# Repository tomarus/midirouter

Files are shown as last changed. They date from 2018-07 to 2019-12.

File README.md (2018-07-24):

FPGA/Verilog MIDI Mixer
=======================

See also: 

* https://github.com/tomarus/v-midi
* https://github.com/tomarus/midiseq

This is a "production" version of my FPGA MIDI router.

My v-midi project is more experimental, this one is tuned for my own hardware.

# Disclaimer

Do not use this to learn Verilog or FPGA stuff.

This is my own personal experimental project.

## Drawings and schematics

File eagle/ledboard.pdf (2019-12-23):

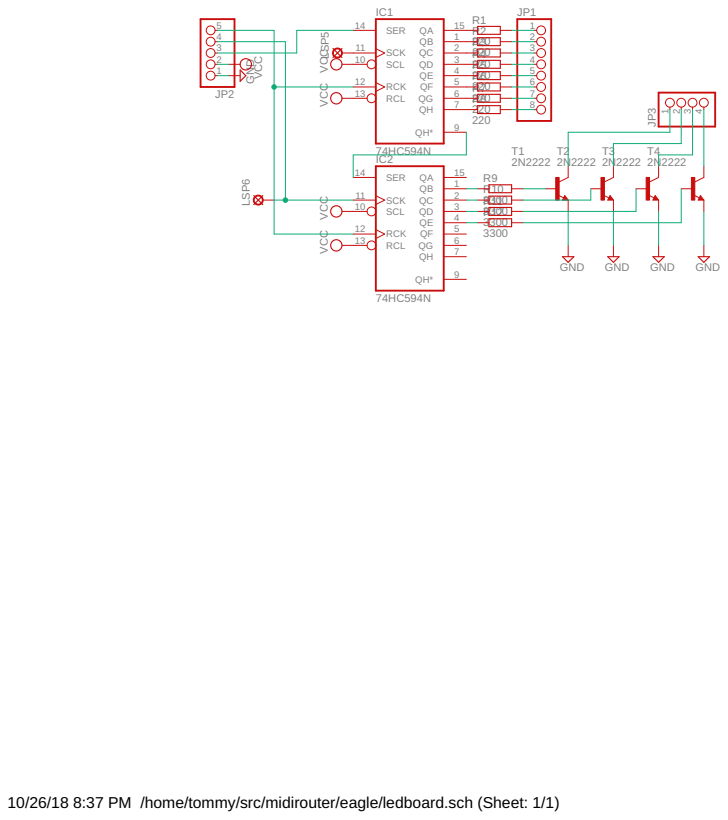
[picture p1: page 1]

VCC VCC

220 R4 3 QE
220 R5 4 QF

10/26/18 8:37 PM /home/tommy/src/midirouter/eagle/ledboard.sch (Sheet: 1/1)

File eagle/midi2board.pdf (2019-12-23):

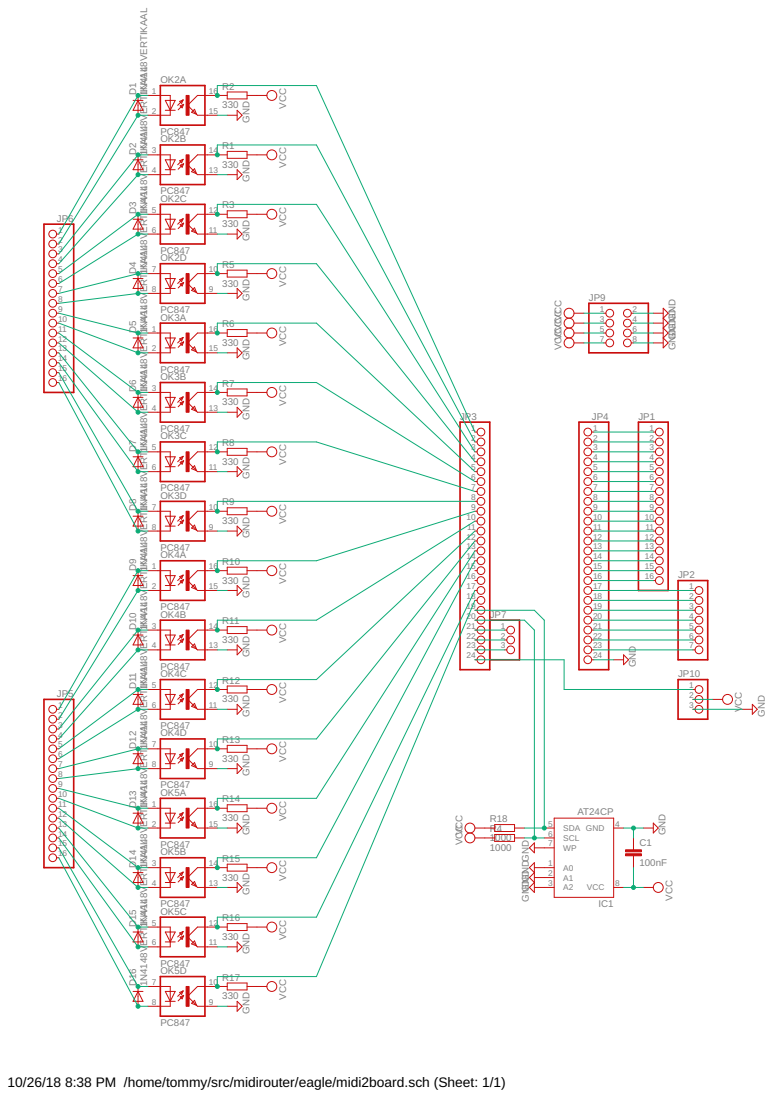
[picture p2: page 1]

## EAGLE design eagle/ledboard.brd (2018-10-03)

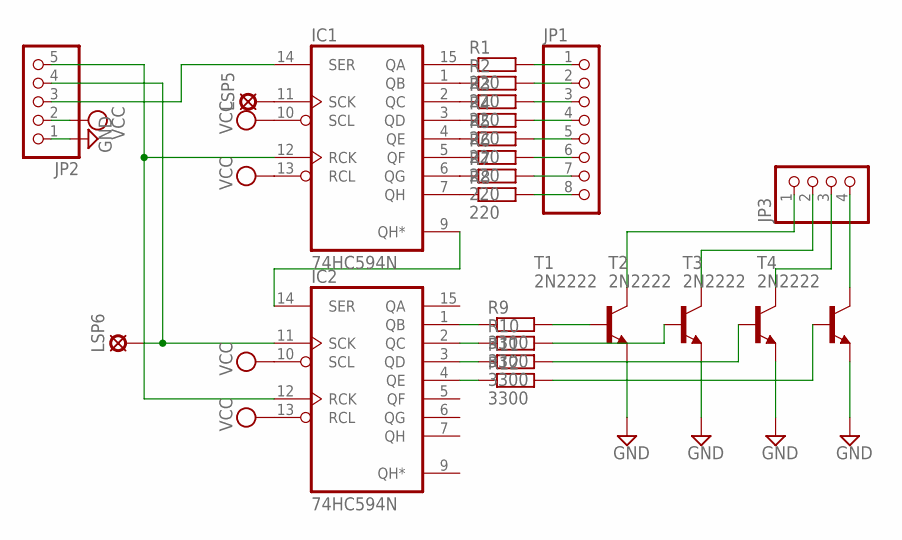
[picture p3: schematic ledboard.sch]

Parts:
IC1, IC2: 74HC594N; DIL16
JP1: PINHD-1X8; 1X08
JP2: PINHD-1X5; 1X05
JP3: PINHD-1X4; 1X04
LSP5, LSP6: LSP10
R1, R2, R3, R4, R5, R6, R7, R8: 220; 0207/10
R9, R10, R11, R12: 3300; 0207/10
T1, T2, T3, T4: 2N2222; TO92-EBC-OVAL

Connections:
GND: IC1.8 (GND), IC2.8 (GND), JP2.1, T1.E, T2.E, T3.E, T4.E
unnamed: IC1.14 (SER), JP2.3
unnamed: IC1.11 (SCK), LSP5.MP
unnamed: IC1.15 (QA), R1.1
unnamed: IC1.1 (QB), R2.1
unnamed: IC1.2 (QC), R3.1
unnamed: IC1.3 (QD), R4.1
unnamed: IC1.4 (QE), R5.1
unnamed: IC1.5 (QF), R6.1
unnamed: IC1.6 (QG), R7.1
unnamed: IC1.7 (QH), R8.1
unnamed: IC2.3 (QD), R11.1
unnamed: IC2.2 (QC), R10.1
unnamed: IC2.1 (QB), R9.1
unnamed: IC2.4 (QE), R12.1
unnamed: R9.2, T1.B
unnamed: R10.2, T2.B
unnamed: R11.2, T3.B
unnamed: R12.2, T4.B
unnamed: JP1.1, R1.2
unnamed: JP1.2, R2.2
unnamed: JP1.3, R3.2
unnamed: JP1.4, R4.2
unnamed: JP1.5, R5.2
unnamed: JP1.6, R6.2
unnamed: JP1.7, R7.2
unnamed: JP1.8, R8.2
unnamed: JP3.1, T1.C
unnamed: JP3.2, T2.C
unnamed: JP3.3, T3.C
unnamed: JP3.4, T4.C
unnamed: IC2.11 (SCK), JP2.4, LSP6.MP
unnamed: IC1.12 (RCK), IC2.12 (RCK), JP2.5
unnamed: IC1.9 (QH*), IC2.14 (SER)
VCC: IC1.10 (SCL), IC1.13 (RCL), IC1.16 (VCC), IC2.10 (SCL), IC2.13 (RCL), IC2.16 (VCC), JP2.2

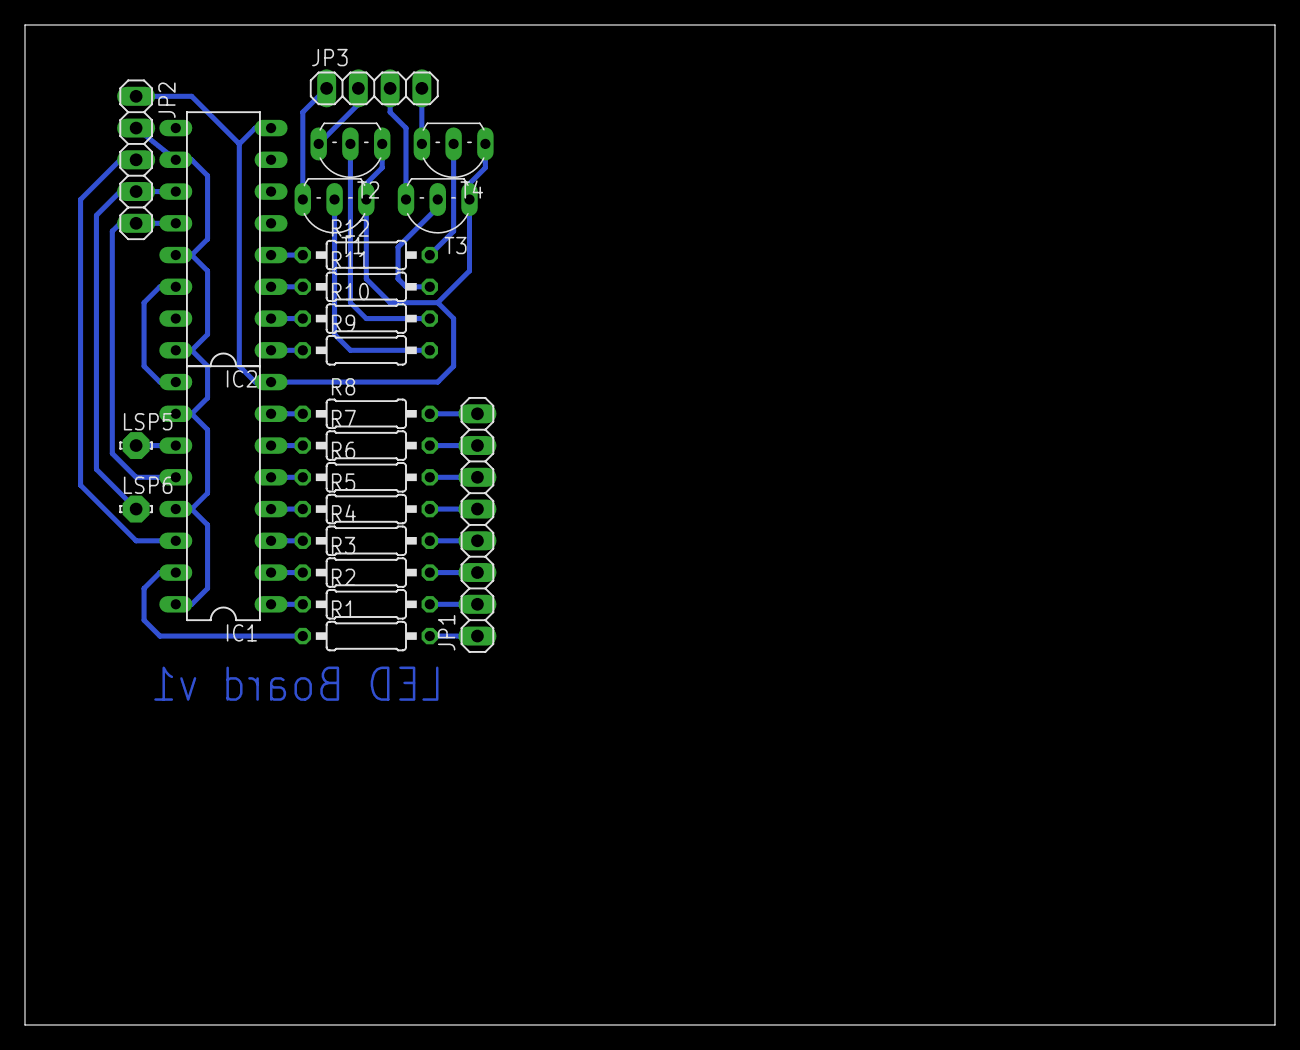
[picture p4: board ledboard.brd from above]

Board: 2 copper layers, 100.0 x 80.0 mm, 23 parts (0 on the bottom side), 35 nets.

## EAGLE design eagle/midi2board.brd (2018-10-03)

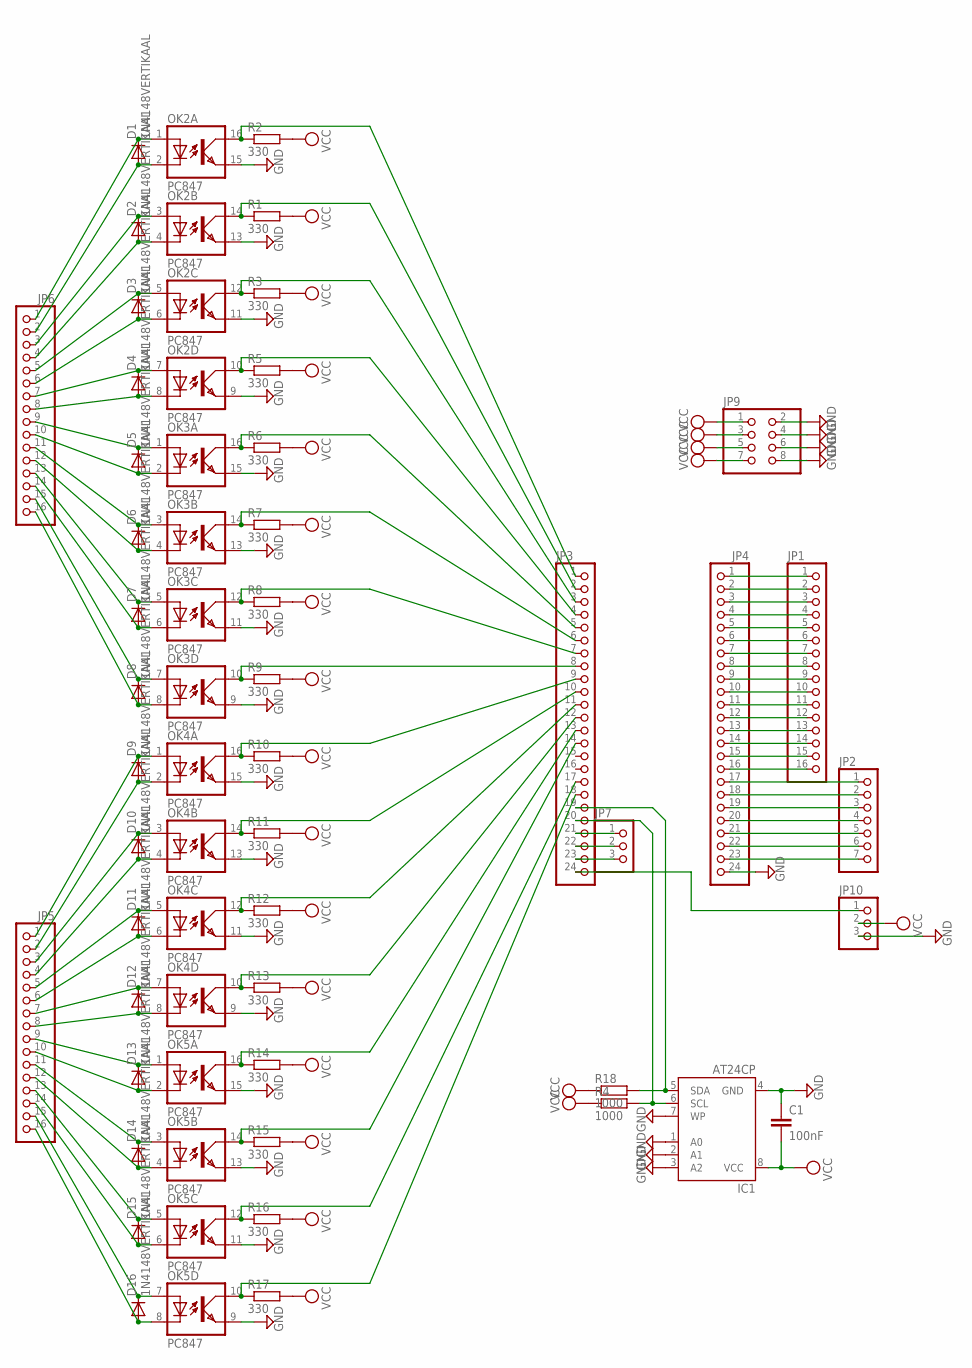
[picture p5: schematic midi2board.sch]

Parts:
C1: 100nF; C5B2.5
D1, D2, D3, D4, D5, D6, D7, D8, D9, D10, D11, D12, D13, D14, D15, D16: 1N4148VERTIKAAL; RAD2,5
IC1: AT24CP; DIL08
JP1, JP5, JP6: PINHD-1X16; 1X16
JP2: PINHD-1X7; 1X07
JP3, JP4: PINHD-1X24; 1X24
JP7, JP10: PINHD-1X3; 1X03
JP9: PINHD-2X4; 2X04
OK2, OK3, OK4, OK5: PC847; DIL16
R1, R2, R3, R5, R6, R7, R8, R9, R10, R11, R12, R13, R14, R15, R16, R17: 330; 0207/10
R4, R18: 1000; 0207/10

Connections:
GND: C1.1, IC1.1 (A0), IC1.2 (A1), IC1.3 (A2), IC1.4 (GND), IC1.7 (WP), JP4.24, JP9.2, JP9.4, JP9.6, JP9.8, JP10.3, OK2.9 (EMIT), OK2.11 (EMIT), OK2.13 (EMIT), OK2.15 (EMIT), OK3.9 (EMIT), OK3.11 (EMIT), OK3.13 (EMIT), OK3.15 (EMIT), OK4.9 (EMIT), OK4.11 (EMIT), OK4.13 (EMIT), OK4.15 (EMIT), OK5.9 (EMIT), OK5.11 (EMIT), OK5.13 (EMIT), OK5.15 (EMIT)
unnamed: JP2.1, JP4.17
unnamed: D1.C, JP6.1, OK2.1 (A)
unnamed: D1.A, JP6.2, OK2.2 (C)
unnamed: JP2.2, JP4.18
unnamed: JP2.3, JP4.19
unnamed: D2.C, JP6.3, OK2.3 (A)
unnamed: D2.A, JP6.4, OK2.4 (C)
unnamed: JP2.4, JP4.20
unnamed: D3.C, JP6.5, OK2.5 (A)
unnamed: D3.A, JP6.6, OK2.6 (C)
unnamed: D4.C, JP6.7, OK2.7 (A)
unnamed: D4.A, JP6.8, OK2.8 (C)
unnamed: D5.C, JP6.9, OK3.1 (A)
unnamed: D5.A, JP6.10, OK3.2 (C)
unnamed: D6.C, JP6.11, OK3.3 (A)
unnamed: D6.A, JP6.12, OK3.4 (C)
unnamed: D7.C, JP6.13, OK3.5 (A)
unnamed: D7.A, JP6.14, OK3.6 (C)
unnamed: D8.C, JP6.15, OK3.7 (A)
unnamed: D8.A, JP6.16, OK3.8 (C)
unnamed: D9.C, JP5.1, OK4.1 (A)
unnamed: D9.A, JP5.2, OK4.2 (C)
unnamed: D10.C, JP5.3, OK4.3 (A)
unnamed: D10.A, JP5.4, OK4.4 (C)
unnamed: D11.C, JP5.5, OK4.5 (A)
unnamed: D11.A, JP5.6, OK4.6 (C)
unnamed: D12.C, JP5.7, OK4.7 (A)
unnamed: D12.A, JP5.8, OK4.8 (C)
unnamed: D13.C, JP5.9, OK5.1 (A)
unnamed: D13.A, JP5.10, OK5.2 (C)
unnamed: D14.C, JP5.11, OK5.3 (A)
unnamed: D14.A, JP5.12, OK5.4 (C)
unnamed: D15.C, JP5.13, OK5.5 (A)
unnamed: D15.A, JP5.14, OK5.6 (C)
unnamed: D16.C, JP5.15, OK5.7 (A)
unnamed: D16.A, JP5.16, OK5.8 (C)
unnamed: JP3.2, OK2.14 (COL), R1.1
unnamed: JP3.1, OK2.16 (COL), R2.1
unnamed: JP3.3, OK2.12 (COL), R3.1
unnamed: JP3.4, OK2.10 (COL), R5.1
unnamed: JP3.5, OK3.16 (COL), R6.1
unnamed: JP3.6, OK3.14 (COL), R7.1
unnamed: JP3.7, OK3.12 (COL), R8.1
unnamed: JP3.8, OK3.10 (COL), R9.1
unnamed: JP3.9, OK4.16 (COL), R10.1
unnamed: JP3.10, OK4.14 (COL), R11.1
unnamed: JP3.11, OK4.12 (COL), R12.1
unnamed: JP3.12, OK4.10 (COL), R13.1
unnamed: JP3.13, OK5.16 (COL), R14.1
unnamed: JP3.14, OK5.14 (COL), R15.1
unnamed: JP3.17, OK5.12 (COL), R16.1
unnamed: JP3.18, OK5.10 (COL), R17.1
unnamed: JP3.24, JP10.1
unnamed: JP3.21, JP7.1
unnamed: JP3.22, JP7.2
unnamed: JP3.23, JP7.3
unnamed: JP1.1, JP4.1
unnamed: JP1.2, JP4.2
unnamed: JP1.3, JP4.3
unnamed: JP1.4, JP4.4
unnamed: JP1.5, JP4.5
unnamed: JP1.6, JP4.6
unnamed: JP1.7, JP4.7
unnamed: JP1.8, JP4.8
unnamed: JP1.9, JP4.9
unnamed: JP1.10, JP4.10
unnamed: JP1.11, JP4.11
unnamed: JP1.12, JP4.12
unnamed: JP1.13, JP4.13
unnamed: JP1.14, JP4.14
unnamed: JP1.15, JP4.15
unnamed: JP1.16, JP4.16
unnamed: JP2.5, JP4.21
unnamed: JP2.6, JP4.22
unnamed: JP2.7, JP4.23
unnamed: IC1.5 (SDA), JP3.19, R18.2
unnamed: IC1.6 (SCL), JP3.20, R4.2
VCC: C1.2, IC1.8 (VCC), JP9.1, JP9.3, JP9.5, JP9.7, JP10.2, R1.2, R2.2, R3.2, R4.1, R5.2, R6.2, R7.2, R8.2, R9.2, R10.2, R11.2, R12.2, R13.2, R14.2, R15.2, R16.2, R17.2, R18.1

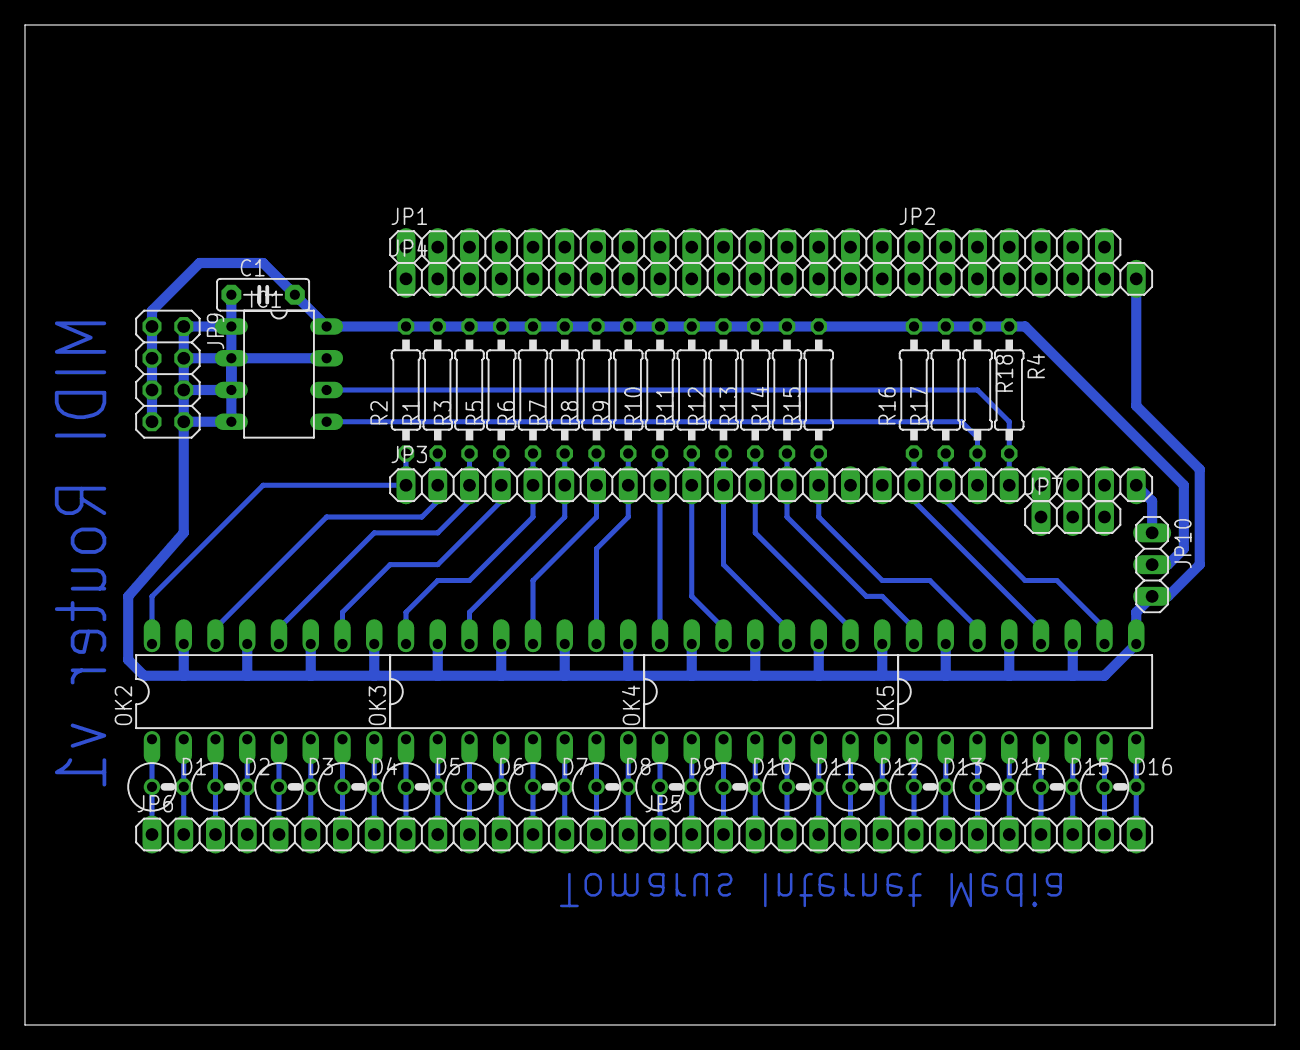
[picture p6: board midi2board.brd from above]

Board: 2 copper layers, 100.0 x 80.0 mm, 49 parts (0 on the bottom side), 79 nets.

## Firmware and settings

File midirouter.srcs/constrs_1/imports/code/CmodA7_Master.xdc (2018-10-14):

## This file is a general .xdc for the CmodA7 rev. B
## To use it in a project:
## - uncomment the lines corresponding to used pins
## - rename the used ports (in each line, after get_ports) according to the top level signal names in the project

## Clock signal 12 MHz
set_property -dict {PACKAGE_PIN L17 IOSTANDARD LVCMOS33} [get_ports clk]
create_clock -period 83.330 -name sys_clk_pin -waveform {0.000 41.660} -add [get_ports clk]


## LEDs
set_property -dict {PACKAGE_PIN A17 IOSTANDARD LVCMOS33} [get_ports {led[0]}]
set_property -dict {PACKAGE_PIN C16 IOSTANDARD LVCMOS33} [get_ports {led[1]}]

set_property -dict { PACKAGE_PIN B17   IOSTANDARD LVCMOS33 } [get_ports { led0_b }]; #IO_L14N_T2_SRCC_16 Sch=led0_b
set_property -dict { PACKAGE_PIN B16   IOSTANDARD LVCMOS33 } [get_ports { led0_g }]; #IO_L13N_T2_MRCC_16 Sch=led0_g
set_property -dict { PACKAGE_PIN C17   IOSTANDARD LVCMOS33 } [get_ports { led0_r }]; #IO_L14P_T2_SRCC_16 Sch=led0_r


## Buttons
#set_property -dict { PACKAGE_PIN A18   IOSTANDARD LVCMOS33 } [get_ports { btn[0] }]; #IO_L19N_T3_VREF_16 Sch=btn[0]
#set_property -dict { PACKAGE_PIN B18   IOSTANDARD LVCMOS33 } [get_ports { btn[1] }]; #IO_L19P_T3_16 Sch=btn[1]


## Pmod Header JA
#set_property -dict { PACKAGE_PIN G17   IOSTANDARD LVCMOS33 } [get_ports { ja[0] }]; #IO_L5N_T0_D07_14 Sch=ja[1]
#set_property -dict { PACKAGE_PIN G19   IOSTANDARD LVCMOS33 } [get_ports { ja[1] }]; #IO_L4N_T0_D05_14 Sch=ja[2]
#set_property -dict { PACKAGE_PIN N18   IOSTANDARD LVCMOS33 } [get_ports { ja[2] }]; #IO_L9P_T1_DQS_14 Sch=ja[3]
#set_property -dict { PACKAGE_PIN L18   IOSTANDARD LVCMOS33 } [get_ports { ja[3] }]; #IO_L8P_T1_D11_14 Sch=ja[4]
#set_property -dict { PACKAGE_PIN H17   IOSTANDARD LVCMOS33 } [get_ports { ja[4] }]; #IO_L5P_T0_D06_14 Sch=ja[7]
#set_property -dict { PACKAGE_PIN H19   IOSTANDARD LVCMOS33 } [get_ports { ja[5] }]; #IO_L4P_T0_D04_14 Sch=ja[8]
#set_property -dict { PACKAGE_PIN J19   IOSTANDARD LVCMOS33 } [get_ports { ja[6] }]; #IO_L6N_T0_D08_VREF_14 Sch=ja[9]
#set_property -dict { PACKAGE_PIN K18   IOSTANDARD LVCMOS33 } [get_ports { ja[7] }]; #IO_L8N_T1_D12_14 Sch=ja[10]


## Analog XADC Pins
## Only declare these if you want to use pins 15 and 16 as single ended analog inputs. pin 15 -> vaux4, pin16 -> vaux12
#set_property -dict { PACKAGE_PIN G2    IOSTANDARD LVCMOS33 } [get_ports { xa_n[0] }]; #IO_L1N_T0_AD4N_35 Sch=ain_n[15]
#set_property -dict { PACKAGE_PIN G3    IOSTANDARD LVCMOS33 } [get_ports { xa_p[0] }]; #IO_L1P_T0_AD4P_35 Sch=ain_p[15]
#set_property -dict { PACKAGE_PIN J2    IOSTANDARD LVCMOS33 } [get_ports { xa_n[1] }]; #IO_L2N_T0_AD12N_35 Sch=ain_n[16]
#set_property -dict { PACKAGE_PIN H2    IOSTANDARD LVCMOS33 } [get_ports { xa_p[1] }]; #IO_L2P_T0_AD12P_35 Sch=ain_p[16]
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

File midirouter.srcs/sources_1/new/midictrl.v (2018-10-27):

`timescale 1ns / 1ps
// Create Date: 07/06/2018 12:52:50 PM
// Module Name: midictrl

module midictrl #( 
	parameter PORTS = 16,
	parameter CLKS_PER_BIT = 384
) (
	input   clk,
	input   rst,
	input   [PORTS-1:0] inport,
	output  [PORTS-1:0] outport,
	output  [PORTS-1:0] activity_in,
	output  [PORTS-1:0] activity_out
);

reg  [PORTS-1:0]   txdv = 0;
reg  [PORTS*8-1:0] txdata = 0;
wire [PORTS*8-1:0] rxdata;
reg  [PORTS*4-1:0] txcurport = 0;
wire [PORTS-1:0]   rx_empty;
reg  [PORTS-1:0]   rx_rden = 0;

reg [15:0] ledclk;
reg ledclken;
always @(posedge clk) begin
	ledclk <= ledclk + 1;
	if (ledclk == 0) ledclken <= 1;
	else ledclken <= 0;
end

midi_port #(.CLKS_PER_BIT(CLKS_PER_BIT), .PORTS(PORTS)) 
	ports[PORTS-1:0] 
	(clk, rst, txdv, outport, txdata, inport, rxdata, activity_in, activity_out, txcurport, rx_empty, rx_rden, ledclken);

reg [63:0] cfg_in_filter = 64'hffffffffffffffff;
reg [63:0] cfg_in_router = 64'hffffffffffffffff;

reg [4:0]port = 0;

reg reset_running = 0;
reg [3:0] reset_counter = 0;
reg [3:0] chcnt = 0;
reg [2:0] msgcnt = 0;

reg sysex_running = 0;
reg [16*8-1:0] sxdata = 0; // 16 * 8 bits of sysex command max
reg [4:0] sxpos = 0;

reg [PORTS*2-1:0] portstate = 0;

reg [3:0] checkport = 2;
reg [2:0] checkstate = 0;

always @(posedge clk)
begin
	txdv[PORTS-1:0] <= 0;

	if (reset_running)
		runreset();
	else if (rst) begin
		reset_counter <= 0;
		// reset_running <= 1;
		chcnt <= 0;
		msgcnt <= 0;
	end
	else begin
		if (sysex_running) runsysex();

		case (checkstate)
		3'b000: begin
			checkport <= checkport + 1;
			if (checkport == 6) begin
				checkport <= 8;
			end
			checkstate <= 3'b001;
		end
		3'b001: begin
			if (!rx_empty[checkport]) begin
				rx_rden[checkport] <= 1;
				checkstate <= 3'b010;
			end
			else begin
				rx_rden[checkport] <= 0;
				checkstate <= 3'b000;
			end
		end
		3'b010: begin
			rx_rden[checkport] <= 0;
			checkstate <= 3'b011;
		end
		3'b011: begin
			handlebyte(checkport, rxdata[checkport*8+:8], portstate[checkport*2+:2]);
			checkstate <= 3'b100;
		end
		3'b100: begin
			checkstate <= 3'b000;
		end
		default: begin
			checkstate <= 3'b000;
		end
		endcase
	end
end

localparam s_IDLE = 2'b00;
localparam s_DATA = 2'b01;
localparam s_SYSEX = 2'b10;

localparam sx_BEGIN = 2'b00;
localparam sx_ID1 = 2'b01;
localparam sx_ID2 = 2'b10;
localparam sx_BUF = 2'b11;
reg [PORTS*2-1:0] sxstate = 0;

task handlebyte;
input [3:0] port;
input [7:0] inbyte;
input [1:0] state;
begin
	case (inbyte[7])
	// command
	1'b1:
		begin
			case (inbyte[7:0])
			8'hff: ; // ignore system reset
			8'hfe: ; // ignore active sensing
			8'hf0: begin
				portstate[port*2+:2] <= s_SYSEX;
				sxstate[port*2+:2] <= sx_BEGIN;
				notallportmsg(inbyte, port);
			end
			8'hf7: begin
				portstate[port*2+:2] <= s_IDLE;
				sysex_running <= 1;
				reset_counter <= 0;
				chcnt <= 0;
				notallportmsg(inbyte, port);
			end
			default: begin
				notallportmsg(inbyte, port);
			end
			endcase
		end
	 // data
	 1'b0:
		begin
			notallportmsg(inbyte, port);

			case (state[1:0])
//            s_IDLE:
//            s_DATA:
			s_SYSEX:
				begin
				 handlesysex(port, inbyte[7:0]);
				end
			default: ;
			endcase
		end
	endcase
end
endtask

//  output.send
//      0xf0, 0x7d,        // sysex, non commercial / educational manufacturer id.
//      0x2a, 0x4d,        // my own little secret magic number id for this router.
//      0x00,              // COMMAND 0x00 = request sysex config dump.
//      0xf7
//  response = 0xf0, 0x7d, 0x2a, 0x4d,
//      0x40, 0x01,            // RESPONSE 0x40, version 1
//      0x01, 0x02,            // 1 inport, 2 outports
//      byte(int(bpm) >> 7),   // current speet msb
//      byte(int(bpm) & 0x7f), // current speed lsb
//      0xf7

reg [11*8-1:0] cfg = 88'hf0_7d_2a_4d_40_01_0f_0f_00_70_f7;

reg [13:0] sxdelay = 0;

task runsysex;
begin
	if (sxpos == 0 || sxdata[7:0] != 0) begin // cnd 0 = request config dunp
//    if (sxpos == 0) begin // cnd 0 = request config dunp
		sysex_running <= 0;
	end
	else begin
		sxdelay <= sxdelay + 1;
		if (sxdelay == 3840) begin
			sxdelay <= 0;
			allportmsg(cfg[(11-reset_counter)*8+:8]);
			reset_counter <= reset_counter + 1;
			if (reset_counter == 4'd11) begin
				sysex_running <= 0;
			end
		end
	end
end
endtask

task handlesysex;
input [3:0]port;
input [7:0]inbyte;
begin
   case (sxstate[port*2+:2])
	sx_BEGIN: begin
		if (inbyte[7:0] == 8'h7d) sxstate[port*2+:2] <= sx_ID1;
	end
	sx_ID1: begin
		if (inbyte[7:0] == 8'h2a) sxstate[port*2+:2] <= sx_ID2;
	end
	sx_ID2: begin
		if (inbyte[7:0] == 8'h4d) begin
			sxstate[port*2+:2] <= sx_BUF;
			sxpos[4:0] <= 0;
		end
	end
	sx_BUF:
		begin
			sxdata[sxpos*8+:8] <= inbyte[7:0];
			sxpos <= sxpos + 1;
		end
	endcase
end
endtask

// reset

task runreset;
begin
	sxdelay <= sxdelay + 1;
	if (sxdelay == 3840) begin
		sxdelay <= 0;
	case (reset_counter)
	4'h0: begin
		allportmsg(8'hfc);
		reset_counter <= reset_counter + 1;
	end
	4'h1: begin
		allportallchmsg(8'hb0, 8'h78, 8'h00); // All sound off
	end
	4'h2: begin
		allportallchmsg(8'hb0, 8'h79, 8'h00); // Reset all controllers
	end
	4'h3: begin
		allportallchmsg(8'hb0, 8'h7b, 8'h00); // All notes off
	end
	4'h4: begin
		reset_running <= 0;
	end
	default:
		reset_running <= 0;
	endcase
	end
end
endtask

task allportallchmsg;
input [7:0]msg1, msg2, msg3;
begin
	case (msgcnt)
	3'b000: begin
		allportmsg(msg1 + chcnt);
		msgcnt <= msgcnt + 1;
	end
	3'b001: begin
		allportmsg(msg2);
		msgcnt <= msgcnt + 1;
	end
	3'b010: begin
		allportmsg(msg3);
		msgcnt <= 0;

		if (chcnt == 4'd15) begin
			reset_counter <= reset_counter + 1;
			chcnt <= 0;
		end
		else begin
			chcnt <= chcnt + 1;
		end
	end
	default:
		msgcnt <= 0;
	endcase
end
endtask

reg [4:0]port_apmsg = 0;
task allportmsg;
input [7:0]msg;
	for (port_apmsg=0; port_apmsg<PORTS; port_apmsg=port_apmsg+1) begin
		sendbyte(port_apmsg, msg, -1); // TODO: -1
	end
endtask

task notallportmsg;
input [7:0]msg;
input [3:0]current_port;
	for (port_apmsg=0; port_apmsg<PORTS; port_apmsg=port_apmsg+1) begin
		if (port_apmsg != current_port) begin
			sendbyte(port_apmsg, msg, current_port);
		end
	end
endtask

task sendbyte;
input [3:0] port;
input [7:0] inbyte;
input [3:0] srcport;
begin
	txdata[port*8+:8] <= inbyte[7:0];
	txdv[port] <= 1;
	txcurport[port*4+:4] <= srcport[3:0];
end
endtask

endmodule

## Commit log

2018-07-25 Fix some small stuff.
    [midictrl.v]
2018-07-25 Reverse rows and collums for better power distribution.
2018-07-31 Change activity leds duration and config to 16 ports.
2018-09-02 Small updates to activity leds, avoid looping/routing on current port.
    [midictrl.v]
2018-10-02 Final fix leds
2018-10-03 Add (eagle) schematics and boards.
    [ledboard.brd, ledboard.sch, midi2board.brd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]
2018-10-03 Keep our trace save file.
2018-10-07 Shave off some LUT usage using a global activity-led delay.
2018-10-14 Fix clock byte merging.
    [midi_out.v, midictrl.v]
2018-10-14 Fix some warnings, fix some tabs vs spaces.
    [CmodA7_Master.xdc, midi_out.v, midictrl.v]
2018-10-14 Some more identation & spaces vs tabs fixes.
    [midi_out.v, midictrl.v]
2018-10-27 Shorten led activity flicker, Fix linter warnings, Disable port 7 because its broken.
    [midictrl.v]
2019-12-23 Add some old pdf schematics.
